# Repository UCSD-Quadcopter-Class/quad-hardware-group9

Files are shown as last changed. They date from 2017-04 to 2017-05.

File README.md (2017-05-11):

# CSE 190 - QUAD-HARDWARE

This repo stores all of the files used during the creation of the quadcopter's
hardware design portion of the lab. The main schematic for the quadcopter is
`./quadcopter.sch`. The board file is `./quadcopter.brd`. The CAM files for the
board are in the file `./CAM/Group9-cam.zip`. Routing should be completed and
inspection is in progress.

## What do the Directories Contain?

### `./lbr`

Contains all of the library files used in EAGLE to create the schematic.

### `./datasheets`

Contains all of the datasheets or reference pages for the parts used in the 
quadcopter board.

### `./reference_sch`

Contains the shematics that were used as a reference while creating the 
quadcopter schematic.

### `./design_reviews`

Should contain all of the files that were created during a design review check.

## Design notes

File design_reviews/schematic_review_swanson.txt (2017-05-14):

Nice looking schematic!

1 uF filter caps in motor controllers should be 0.1uF

Your custom LEDS are all backwards.

The pulldown on your custom LED driver is probably not necessary.  There's no harm it being high and they are just two more parts to place and solder.

You don't need netbridge U$7.

The ground on the input side of the voltage converter sohuld bat_gnd

Your pullup resistors on SDA/SCL are too small.  Use 10kOhm.  At 330, it quite possible that the ucontroller and IMU will not be able to pull them low.

A critical pin on your IMU is not connected.  Read the datasheet about what each pin does.

You are missing two decoupling caps for the micro controller.

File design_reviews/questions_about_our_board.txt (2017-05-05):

Group 9 design review

Reviewer: Group 10

Antenna and Antenna Driver
	All check points are satisfied.
	
Power and Ground
	D8 is not above the VBAT power plane. There is a via near the motor driver.
	The 3V power plane is under the IMU and there is a ground via under the IMU.
	The VBAT power plane does not extend to the battery connector.
	
IMU
	3V plane is under the IMU.
	
Headers
	Headers are fine.
	
Microcontroller
	C1 is a little bit far.

Power Supply
	Power supply looks fine.

Motor Drivers
	Yes, the traces are thick enough. 

Aesthetics
	The board look nice.

Mechanical
	The cup is too big for the motor. The diameter should be 8.5mm. 
	It is roughly symmetric.
	No large internal holes.
Checks
	I did not find the DRU file from Group 9 and I used my DRU. There are errors related to stop mask and air wires.
	Eagle lint pass.
	DFM shows missing soldermask clearance as the potential steppers.

Gerber Files
	Antenna area is clear.
	Power planes are corresponding to the board layout.
	There is a motor cup showed on top and bottom copper layer. I am not sure is that correct.
	Outline is fine. 
	The stoppers are mentioned in 'CHECKS'.

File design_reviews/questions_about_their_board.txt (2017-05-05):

From: Group 9
To: Group 10

-- : Critical Design Error
-  : Bad Design Practice
|  : Suggestion/Concerns

Antenna and Antenna Driver
-- Balun -> Antenna trace should be thicker than the default trace width
-- Entirety of antenna is exposed to the ground plane. The ground plane should
   only reach the first trace [See the red board's layout]
-- Vias are surrounding the entire antenna [Should only surround the driver circuit]

Power and Ground
-- Traces seem to change width depending on the component they start from. [This is
   also a DRC complaint.]

IMU
| Some of the traces can be cleaned up, but otherwise fine
| Are you planning to control the quad in an X-layout?

Headers
- FTDI could possible have better information than just GRN/BLK identifiers

Microcontroller
| Oscillator trace lengths should generally be about the same (although it's not really "required")
-- Traces under the microcontroller are pretty crazy and wrap about each other!

Power Supply
- Could the caps C18/C19 be closer to the regulator?
| The area underneath the regulator is free. It could potentially be moved closer to the battery.

Motor Drivers
(Nothing wrong here)

Aesthetics
- Trace Layout looks very nice, with the exception of the traces under the microcontroller!
- Some of the placement references can be realigned such that they won't just be cut off
| Try using the silk to personalize the board! (Even a group name would suffice)!

Mechanical
- Battery placed in the lower half of the board! Board components are small, I doubt that 
   moving the battery to that location would be much better than leaving it in the center!

Checks
-- LED 5mm variant missing required attributes (Eagle Lint)
-- Can't find library 'Yueqi Wang-Lab 2' for LED on schematic (Eagle Lint)
-- There are a few critical clearance issues! [i.e. vias/traces too close to one
   another] Especiall so around the microcontroller! (DRC)
-- There are also a few overlap errors with the wires and vias around the microcontroller.
-- Some pins have different values and thus produce width errors (Are these intentional?
   Some don't seem like power lines.)

Gerber Files
[None were provided, so there were generated by Group 9.]
| Fills in the power plane looked almost like they were going to touch, but since Eagle didn't complain,
   I'll just leave this as more of a warning.
| A trace seems to overlap completely over a component (R8). Is this fine?
| The dashed lines seems to just be a reference. Is it fine to leave it in the dimensions layer?
   (It probably is fine, but I'm not quite sure either).

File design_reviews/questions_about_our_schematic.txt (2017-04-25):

Designer: Group 9

Reviewer: Group 10

LED library
1. The size of pad is smaller than that suggested on the Page 8 in the datasheet.
2. The font of >NAME and >VALUE is in proportional instead of vector in the LED package.
3. R, G, B orientation signs in the package is placed in 49 tReference instead of 51 tDoc.

Lab 2 library
	
	LED
	1. The font of >NAME and >VALUE is in proportional instead of vector in the LED package.
	
	Resistor
	1. The font of >NAME and >VALUE is in proportional instead of vector in the LED package.
	
	IMU
	1. The first 'pad' is drawn by wire instead of pad (Fine).
	2. The font of >NAME is in proportional instead of vector in the LED package.
	
	MOSFET
	1. Pad 'D' is oversize (power dissipation).
	2. The font of >NAME is in proportional instead of vector in the LED package.
	3. Attribute in the device does not include 'value' item.
	
Schematic
1. The location of jumper and net bridge is opposite. Jumper is on the negative terminal and the net bridge is on the positive bridge.

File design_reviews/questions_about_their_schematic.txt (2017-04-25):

Designer: Group 10

Reviewer: Group 9

SCHEM:
1. No jumper present in the positive terminal of the battery
2. No pull-up resistors are placed from SCL/SDA to VDDIO
3. TX/RX pins are flipped on debug FTDI header (JP2)
4. SDO_M is shorted to ground, but it should be shorted to VDDIO
5. No custom LED circuit was created.
6. Motor circuit is wired to the IMU/uC ground. It should be wired to BAT_GND
7. The FLYBACK and FILTERED nodes on the motor circuit are all shorted together.
   Give all of them unique names to prevent this problem.

LBR:
1. It's recommended to give the part oultine in TPlace. [This is an issue for
   all designs]
2. NMOS pads are fine, but power dissipation might become an issue. Make them
   larger to give yourself some room.

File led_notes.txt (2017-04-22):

LED_CIRCUIT_DESIGN_SPEC
-------------------------------------------------------------------------------
:: The previous design was changed due to a misunderstanding about using the ::
:: light intensity per watt instead of using the typical intensity as lumens ::

Now, the circuit uses three red and three royal blue LEDs. Both of these are
considered high-power LEDs and therefore can be used to create a considerable
amount of light. The datasheet is located in the LEDs folder as `creeinc_...`.

From here, I decided to place them in a MOS circuit to be able to control the
brightness using a PWM pin. Since two LEDs would be running for any NMOS in
saturation, the current draw while one is on would be 350mA. It's true that
current draw would be 700mA max when both are on, but assuming I need both
to be on, I could just flash them in sequence quickly to simulate the effect.

Resistance values were calculated using the general equation (and assuming that
the Vds drop for the saturated MOS would be approx. 0V):

    V_BAT - Vd
    -----------
     .175 mA

where V_BAT is the battery voltage at any given moment (max is the most useful),
and Vd is the drop accross the diode (something slightly higher than typical
was used).

One thing to note is that due to their typical current rating of 175mA, the
resistors we generally use could not be used in this application. To remedy
the problem, I introduced two new 1/2 W resistors so that the power dissipation
would be well under the max power rating.

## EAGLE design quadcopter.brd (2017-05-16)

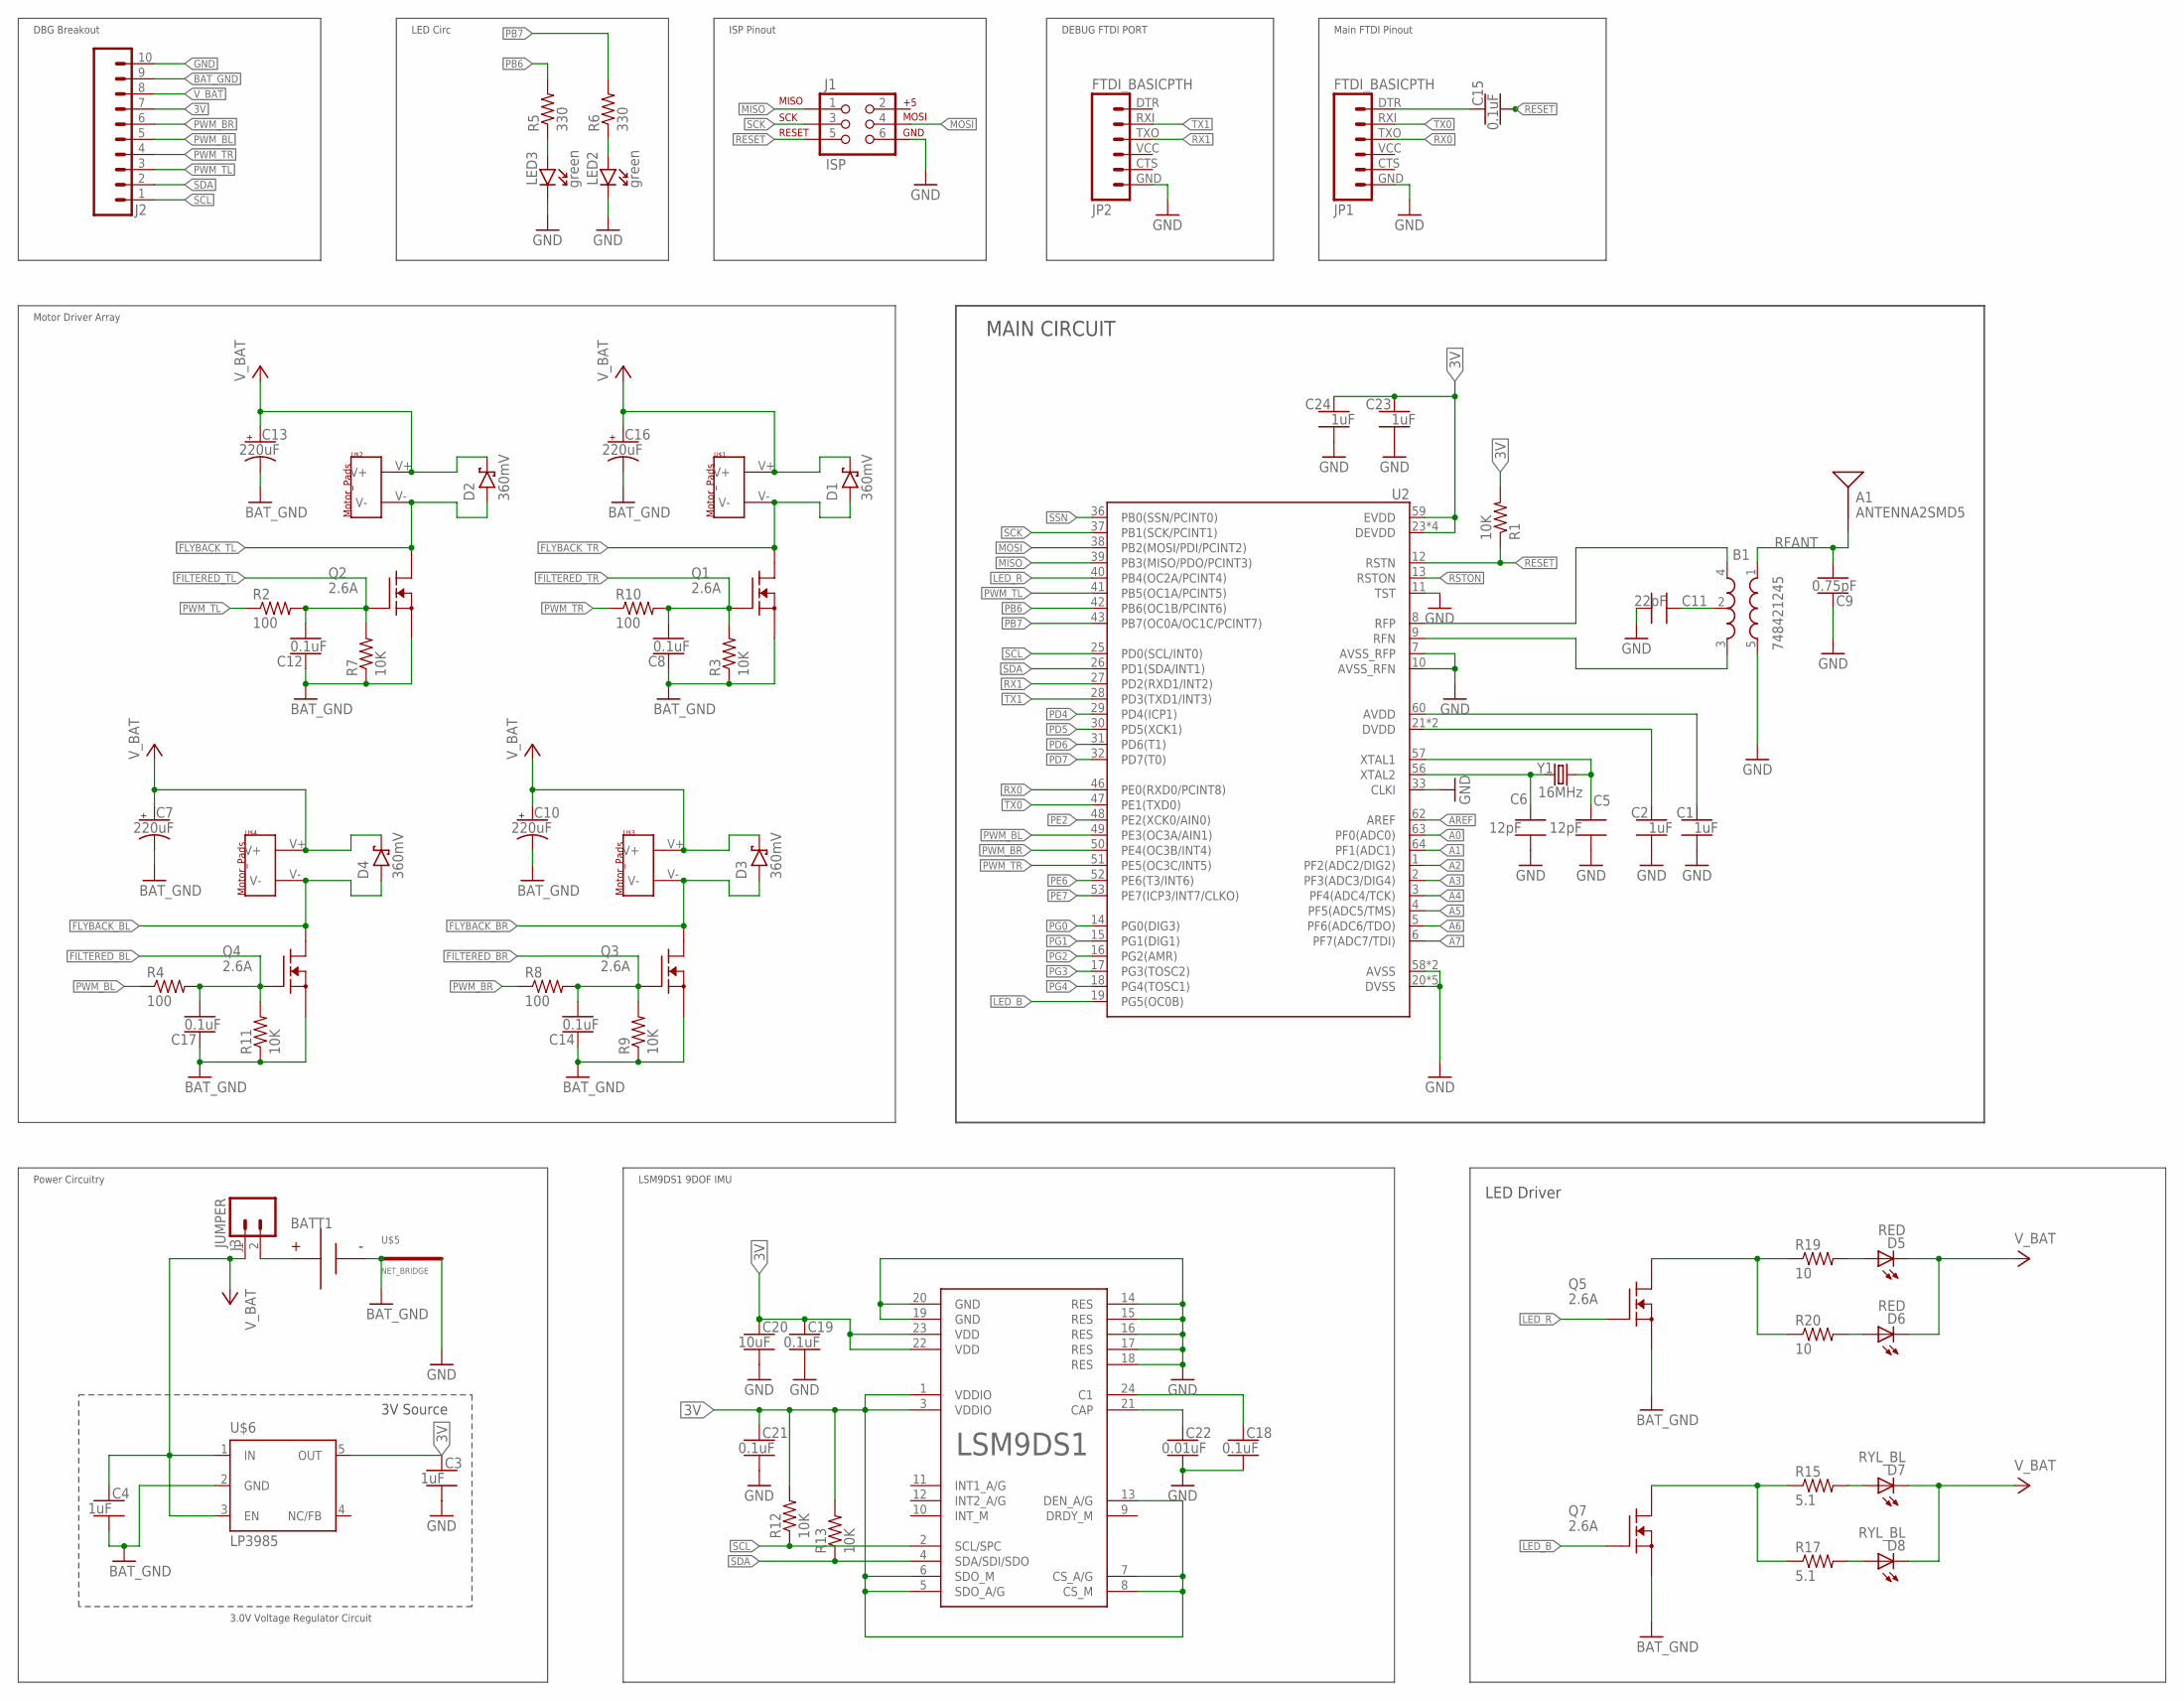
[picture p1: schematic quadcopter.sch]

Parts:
A1: ANTENNA2SMD5; ANTENNA-CHIP5
B1: 748421245; BALUN
BATT1: BATTERY-HUBSAN-W/HOLDER; BATTERY-W/HOLDER-380MAH-HUBSAN
C1, C2, C3, C4, C23, C24: 1uF; CAPC2012X140_HS
C5, C6: 12pF; CAPC2012X140_HS
C7, C10, C13, C16: 220uF; CAPMP7343X310_HS
C8, C12, C14, C15, C17, C18, C19, C21: 0.1uF; CAPC2012X140_HS
C9: 0.75pF; CAPC2012X140_HS
C11: 22pF; CAPC2012X140_HS
C20: 10uF; CAPC2012X140_HS
C22: 0.01uF; CAPC2012X140_HS
D1, D2, D3, D4: 360mV; SOD3716X135_HS
D5, D6: RED; XQ-A-1616
D7, D8: RYL_BL; XQ-A-1616
J1: ISP; 2X3-NS
J2: SIP-10_TH-254X10; HDRV10W63P254_10X1_2540X254H838_HS
J3: JUMPER; MALE_HEADER_2X1_0.1IN
JP1, JP2: FTDI_BASICPTH; FTDI_BASIC
LED2, LED3: green; LEDSC125X200X120-2_HS
LSM9DS1: LSM9DS1_IMU; LSM9DS1_LGA24L
Q1, Q2, Q3, Q4, Q5, Q7: 2.6A; SOT-23
R1, R3, R7, R9, R11, R12, R13: 10K; RESC2012X60_HS
R2, R4, R8, R10: 100; RESC2012X60_HS
R5, R6: 330; RESC2012X60_HS
R15, R17: 5.1; PSC_RESIST_805_LR
R19, R20: 10; PSC_RESIST_805
U2: ATMEGA128RFA1; QFN-64
U$1, U$2, U$3, U$4: MOTOR_PADS
U$5: NET_BRIDGE
U$6: LP3985; SOT23-DBV
Y1: 16MHz; CRYSTAL-SMD-5X3

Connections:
3V: C3.1, C19.1, C20.1, C21.1, C23.1, C24.1, J2.7, LSM9DS1.1 (VDDIO), LSM9DS1.3 (VDDIO), LSM9DS1.5 (SDO_A/G), LSM9DS1.6 (SDO_M), LSM9DS1.7 (CS_A/G), LSM9DS1.8 (CS_M), LSM9DS1.13 (DEN_A/G), LSM9DS1.22 (VDD), LSM9DS1.23 (VDD), R1.2, R12.2, R13.2, U2.23 (DEVDD), U2.34 (DEVDD), U2.44 (DEVDD), U2.54 (DEVDD), U2.59 (EVDD), U$6.5 (OUT)
A0: U2.63 (PF0(ADC0))
A1: U2.64 (PF1(ADC1))
A2: U2.1 (PF2(ADC2/DIG2))
A3: U2.2 (PF3(ADC3/DIG4))
A4: U2.3 (PF4(ADC4/TCK))
A5: U2.4 (PF5(ADC5/TMS))
A6: U2.5 (PF6(ADC6/TDO))
A7: U2.6 (PF7(ADC7/TDI))
AREF: U2.62 (AREF)
AVDD: C1.1, U2.60 (AVDD)
BAT_GND: BATT1.- (N), C4.2, C7.2 (-), C8.1, C10.2 (-), C12.1, C13.2 (-), C14.1, C16.2 (-), C17.1, J2.9, Q1.S, Q2.S, Q3.S, Q4.S, Q5.S, Q7.S, R3.1, R7.1, R9.1, R11.1, U$5.P$1, U$6.2 (GND)
DTR: C15.1, JP1.DTR (1)
DVDD: C2.1, U2.21 (DVDD), U2.22 (DVDD)
FILTERED_BL: C17.2, Q4.G, R4.2, R11.2
FILTERED_BR: C14.2, Q3.G, R8.2, R9.2
FILTERED_TL: C12.2, Q2.G, R2.2, R7.2
FILTERED_TR: C8.2, Q1.G, R3.2, R10.2
FLYBACK_BL: D4.A, Q4.D, U$4.V-
FLYBACK_BR: D3.A, Q3.D, U$3.V-
FLYBACK_TL: D2.A, Q2.D, U$2.V-
FLYBACK_TR: D1.A, Q1.D, U$1.V-
GND: B1.5 (GND), C1.2, C2.2, C3.2, C5.2, C6.2, C9.1, C11.2, C18.2, C19.2, C20.2, C21.2, C22.2, C23.2, C24.2, J1.6, J2.10, JP1.GND (6), JP2.GND (6), LED2.C, LED3.C, LSM9DS1.14 (RES), LSM9DS1.15 (RES), LSM9DS1.16 (RES), LSM9DS1.17 (RES), LSM9DS1.18 (RES), LSM9DS1.19 (GND), LSM9DS1.20 (GND), U2.7 (AVSS_RFP), U2.10 (AVSS_RFN), U2.11 (TST), U2.20 (DVSS), U2.24 (DVSS), U2.33 (CLKI), U2.35 (DVSS), U2.45 (DVSS), U2.55 (DVSS), U2.58 (AVSS), U2.61 (AVSS), U$5.P$2
LED_B: Q7.G, U2.19 (PG5(OC0B))
LED_R: Q5.G, U2.40 (PB4(OC2A/PCINT4))
MISO: J1.1, U2.39 (PB3(MISO/PDO/PCINT3))
MOSI: J1.4, U2.38 (PB2(MOSI/PDI/PCINT2))
unnamed: BATT1.+, J3.2
unnamed: C5.1, U2.57 (XTAL1), Y1.3 (2)
unnamed: C6.1, U2.56 (XTAL2), Y1.1
unnamed: C18.1, LSM9DS1.24 (C1)
unnamed: Q5.D, R19.P$1 (1), R20.P$1 (1)
unnamed: B1.2 (GND), C11.1
unnamed: LED3.A, R5.1
unnamed: C22.1, LSM9DS1.21 (CAP)
unnamed: Q7.D, R15.P$1 (1), R17.P$1 (1)
unnamed: D5.A, R19.P$2 (2)
unnamed: D6.A, R20.P$2 (2)
unnamed: LED2.A, R6.1
unnamed: D7.A, R15.P$2 (2)
unnamed: D8.A, R17.P$2 (2)
PB6: R5.2, U2.42 (PB6(OC1B/PCINT6))
PB7: R6.2, U2.43 (PB7(OC0A/OC1C/PCINT7))
PD4: U2.29 (PD4(ICP1))
PD5: U2.30 (PD5(XCK1))
PD6: U2.31 (PD6(T1))
PD7: U2.32 (PD7(T0))
PE2: U2.48 (PE2(XCK0/AIN0))
PE6: U2.52 (PE6(T3/INT6))
PE7: U2.53 (PE7(ICP3/INT7/CLKO))
PG0: U2.14 (PG0(DIG3))
PG1: U2.15 (PG1(DIG1))
PG2: U2.16 (PG2(AMR))
PG3: U2.17 (PG3(TOSC2))
PG4: U2.18 (PG4(TOSC1))
PWM_BL: J2.5, R4.1, U2.49 (PE3(OC3A/AIN1))
PWM_BR: J2.6, R8.1, U2.50 (PE4(OC3B/INT4))
PWM_TL: J2.3, R2.1, U2.41 (PB5(OC1A/PCINT5))
PWM_TR: J2.4, R10.1, U2.51 (PE5(OC3C/INT5))
RESET: C15.2, J1.5, R1.1, U2.12 (RSTN)
RFANT: A1.FEED, B1.1 (IN), C9.2
RFN: B1.3 (OUT2), U2.9 (RFN)
RFP: B1.4 (OUT1), U2.8 (RFP)
RSTON: U2.13 (RSTON)
RX0: JP1.TXO (3), U2.46 (PE0(RXD0/PCINT8))
RX1: JP2.TXO (3), U2.27 (PD2(RXD1/INT2))
SCK: J1.3, U2.37 (PB1(SCK/PCINT1))
SCL: J2.1, LSM9DS1.2 (SCL/SPC), R12.1, U2.25 (PD0(SCL/INT0))
SDA: J2.2, LSM9DS1.4 (SDA/SDI/SDO), R13.1, U2.26 (PD1(SDA/INT1))
SSN: U2.36 (PB0(SSN/PCINT0))
TX0: JP1.RXI (2), U2.47 (PE1(TXD0))
TX1: JP2.RXI (2), U2.28 (PD3(TXD1/INT3))
V_BAT: C4.1, C7.1 (+), C10.1 (+), C13.1 (+), C16.1 (+), D1.C, D2.C, D3.C, D4.C, D5.C, D6.C, D7.C, D8.C, J2.8, J3.1, U$1.V+, U$2.V+, U$3.V+, U$4.V+, U$6.1 (IN), U$6.3 (EN)

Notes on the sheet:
DEBUG FTDI PORT
ISP Pinout
Main FTDI Pinout
LED Circ
Motor Driver Array
DBG Breakout
Power Circuitry
3.0V Voltage Regulator Circuit
LSM9DS1 9DOF IMU
MAIN CIRCUIT
LED Driver
3V Source

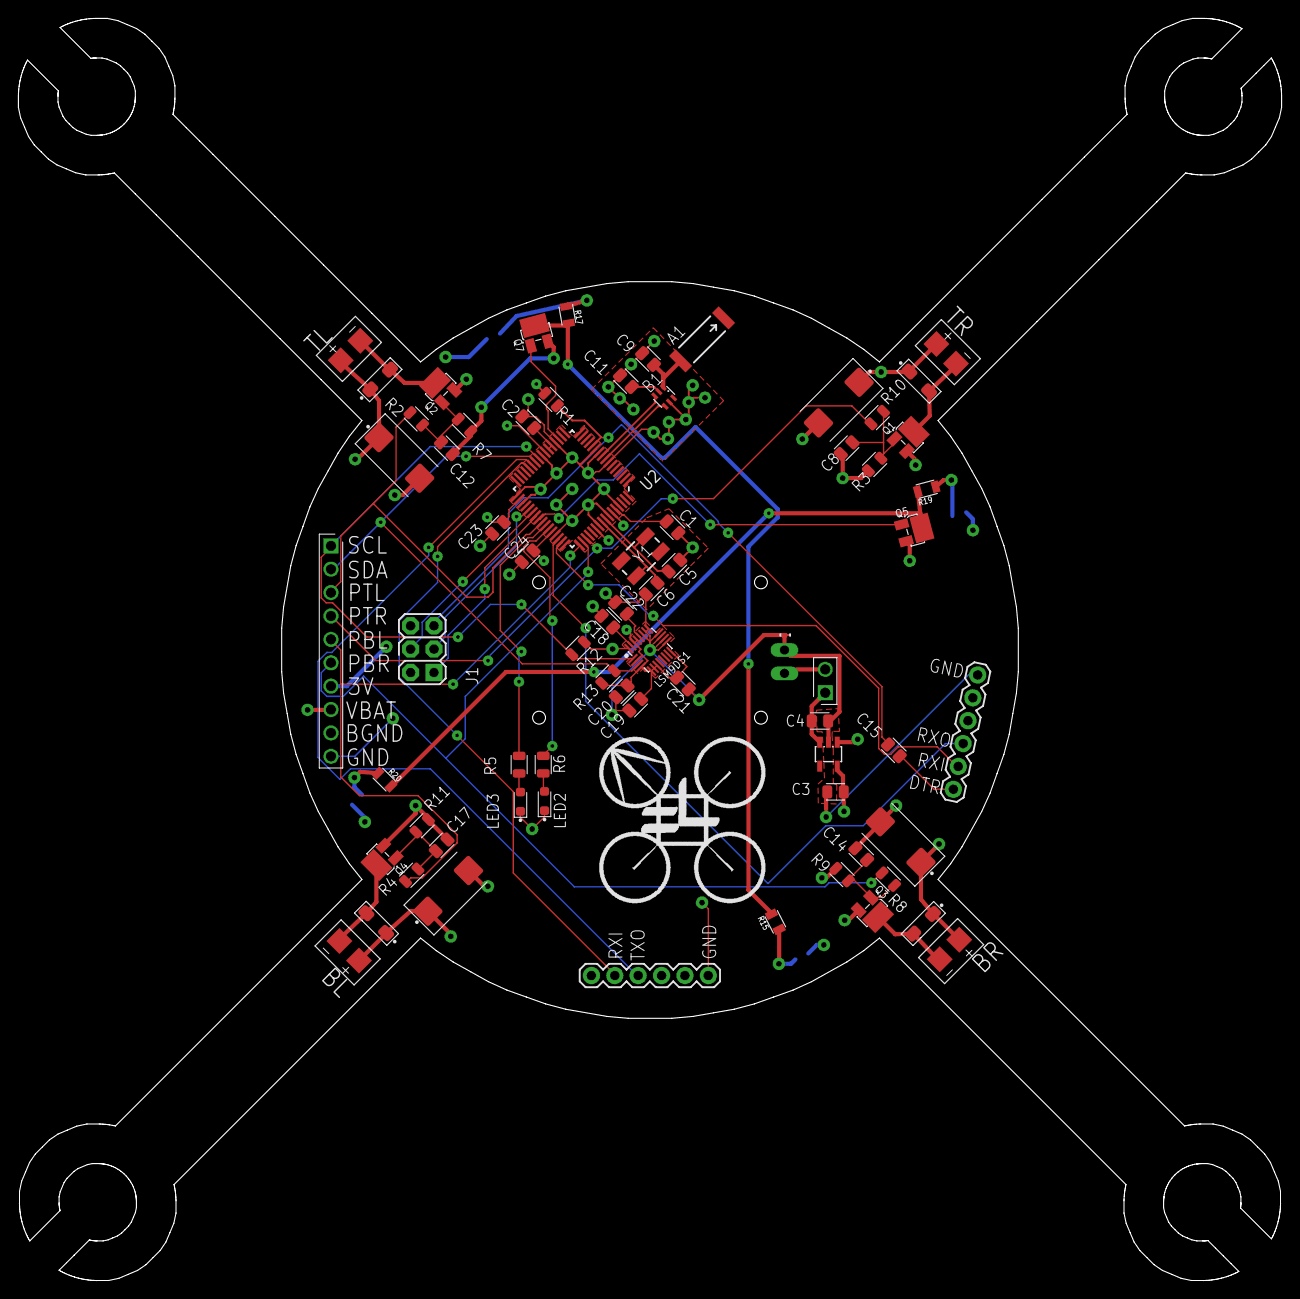
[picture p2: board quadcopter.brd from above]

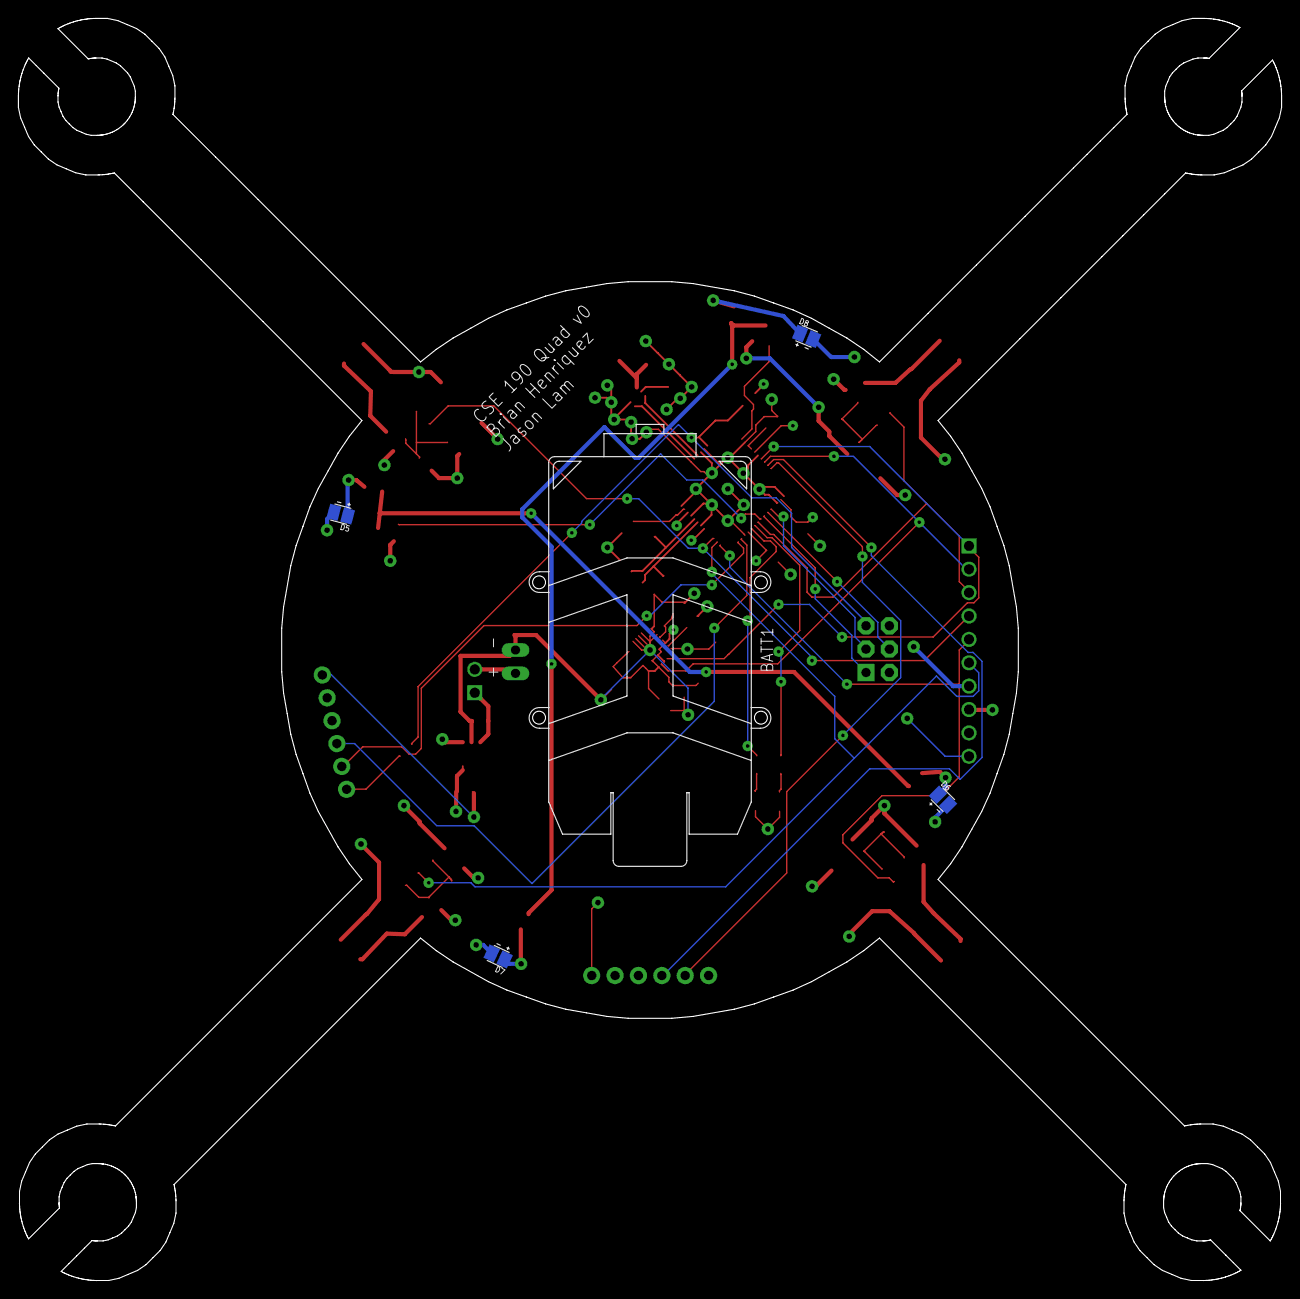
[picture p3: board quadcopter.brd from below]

Board: 4 copper layers, 137.2 x 137.1 mm, 75 parts (5 on the bottom side), 50 nets.

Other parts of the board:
U$7: LOGO_QUAD

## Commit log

2017-04-20 Push initial schematic and documentation
    [ATmega128RFA1-DevBoard.sch, Motor-Driver.sch, quadcopter.sch]
2017-04-22 Fixed a few errors. Revised schematic and docs for new LEDs
    [quadcopter.sch]
2017-04-22 Forgot to commit libraries. Fixed a few errors found on Eagle LINT.
    [quadcopter.sch]
2017-04-24 Fixed jumper placement and PWM pin input.
    [quadcopter.sch]
2017-04-25 Commit design reviews and performed revisions requested.
    [quadcopter.sch]
2017-04-26 Changed schematic slightly. Created basic board layout.
    [quadcopter.brd, quadcopter.sch]
2017-04-26 Moved silkscreen for legibility. Added labels and orientation reference.
    [quadcopter.brd]
2017-04-27 instructior review of original schematic
2017-05-01 Corrected mistakes found on schematics and libraries. Rerouted board from updated schematic.
    [quadcopter.brd, quadcopter.sch]
2017-05-02 Added a logo to the board. Updated libary with logo.
    [quadcopter.brd]
2017-05-05 Forgot to add board design reviews.
2017-05-11 Finished new routing & added cam zip
    [quadcopter.brd]
2017-05-14 more schematic comments from swanson
2017-05-15 Updated board and cam to meet new board review changes.
    [quadcopter.brd, quadcopter.sch]
2017-05-16 Completed board routing
    [quadcopter.brd, quadcopter.sch]

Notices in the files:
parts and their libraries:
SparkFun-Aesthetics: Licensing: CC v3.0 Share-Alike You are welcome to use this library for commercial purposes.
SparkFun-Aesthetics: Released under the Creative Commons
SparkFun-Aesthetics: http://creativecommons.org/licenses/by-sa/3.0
